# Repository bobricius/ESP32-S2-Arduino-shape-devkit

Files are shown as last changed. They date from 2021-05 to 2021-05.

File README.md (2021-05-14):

# ESP32-S2-Arduino-shape-devkit
Simplified Adafruit Metro ESP32-S2

ESP32-S2 development board.

Tested:

0.96" IPS display

#Circuitpython

Arduino IDE

DFU Bootloader

PCB Made in 

@AislerHQ www.aisler.net
 
Thanks 
@adafruit for great work!

Simplified Metro board.

DISPLAY:

  #define TFT_CS         7

  #define TFT_RST        5

  #define TFT_DC         6

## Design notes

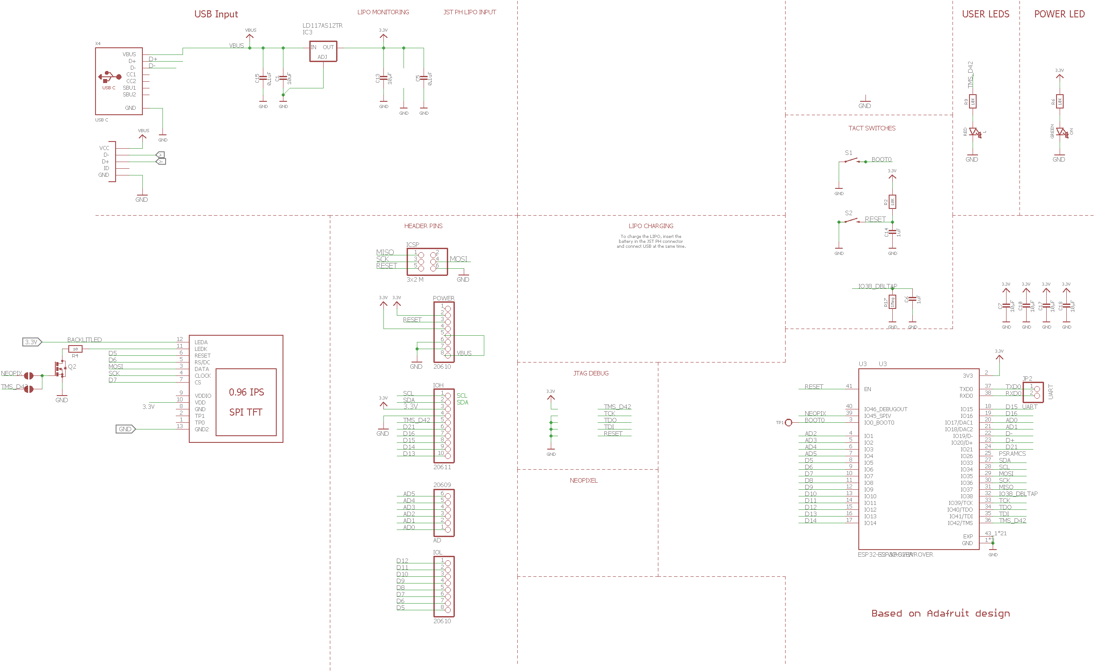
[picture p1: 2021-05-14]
schematic.png

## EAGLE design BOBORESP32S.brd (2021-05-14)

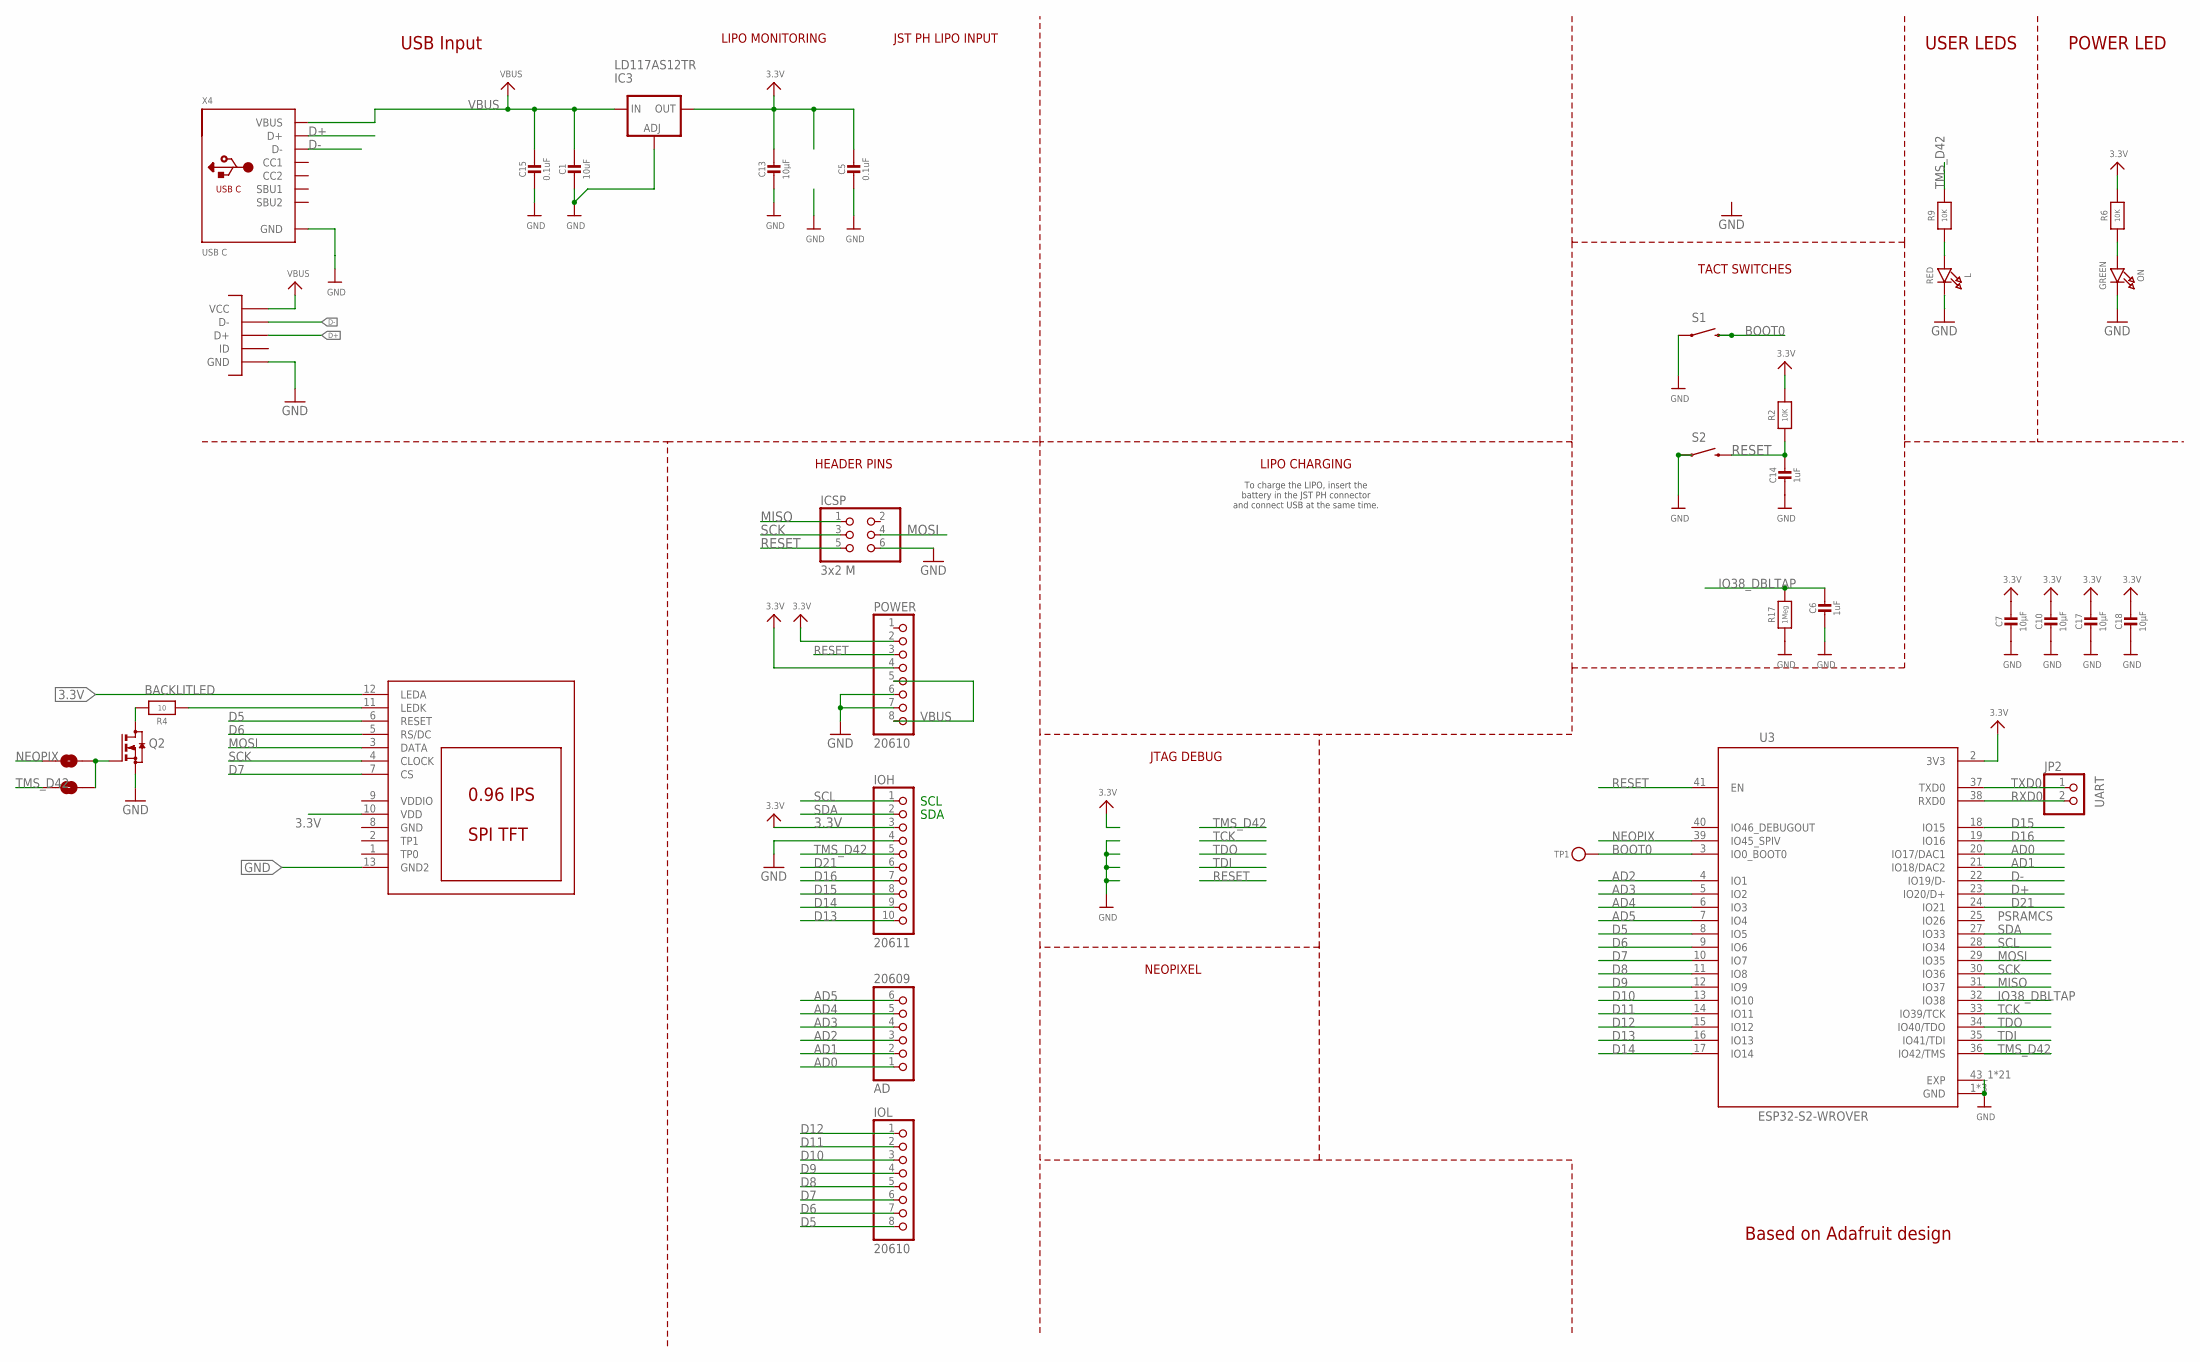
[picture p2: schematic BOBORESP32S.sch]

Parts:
AD: 20609; 1X06_OVALWAVE
C1: 10uF; _0805
C5: 0.1uF; _0805
C6, C14: 1uF; _0603
C7, C10, C13, C17, C18: 10µF; _0805
C15: 0.1uF; _0603
IC3: LD117AS12TR; SOT223
ICSP: 3x2 M; 2X03_ROUND_70MIL
IOH: 20611; 1X10_OVALWAVE
IOL: 20610; 1X08_OVALWAVE
JP2: UART; 1X02_ROUND
JUMPER1: SOLDERJUMPERTRACE; SJ_2S-TRACE
JUMPER2: SOLDERJUMPERNC2; SJ_2S-NOTRACE
L: RED; CHIPLED_0603_NOOUTLINE
ON: GREEN; CHIPLED_0603_NOOUTLINE
POWER: 20610; 1X08_OVALWAVE
Q2: BSS123; SOT23
R2, R6, R9: 10K; 0603-NO
R4: 10; 0603-NO
R17: 1Meg; 0603-NO
S1, S2: SWITCH-MOMENTARY-2PTH; TACTILE-PTH
TP1: TESTPOINTROUND1.5MMNO; TESTPOINT_ROUND_1.5MM_NO
U3: ESP32-S2-WROVER; MODULE_ESP32-S2-WROVER
U$5: MICROUSB; MICRO_B
U$9: DISP_LCD_0.9IN_160X80; TFT_0.96IN_160X80B
X4: USB C; USB_C_CUSB31-CFM2AX-01-X

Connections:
3.3V: C5.1, C7.1, C10.1, C13.1, C17.1, C18.1, IC3.4 (OUT), IOH.3, POWER.2, POWER.4, R2.2, R6.2, U3.2 (3V3), U$9.10 (VDD), U$9.12 (LEDA)
AD0: AD.1, U3.20 (IO17/DAC1)
AD1: AD.2, U3.21 (IO18/DAC2)
AD2: AD.3, U3.4 (IO1)
AD3: AD.4, U3.5 (IO2)
AD4: AD.5, U3.6 (IO3)
AD5: AD.6, U3.7 (IO4)
BACKLITLED: R4.1, U$9.11 (LEDK)
BOOT0: S1.3 (2), TP1.P$1, U3.3 (IO0_BOOT0)
D5: IOL.8, U3.8 (IO5), U$9.6 (RESET)
D6: IOL.7, U3.9 (IO6), U$9.5 (RS/DC)
D7: IOL.6, U3.10 (IO7), U$9.7 (CS)
D8: IOL.5, U3.11 (IO8)
D9: IOL.4, U3.12 (IO9)
D10: IOL.3, U3.13 (IO10)
D11: IOL.2, U3.14 (IO11)
D12: IOL.1, U3.15 (IO12)
D13: IOH.10, U3.16 (IO13)
D14: IOH.9, U3.17 (IO14)
D15: IOH.8, U3.18 (IO15)
D16: IOH.7, U3.19 (IO16)
D21: IOH.6, U3.24 (IO21)
D+: U3.23 (IO20/D+), U$5.P3 (D+), X4.A6 (D+), X4.B6 (D+)
D-: U3.22 (IO19/D-), U$5.P2 (D-), X4.A7 (D-), X4.B7 (D-)
DISPBL: JUMPER1.1, JUMPER2.1, Q2.1 (G)
GND: C1.2, C5.2, C6.2, C7.2, C10.2, C13.2, C14.2, C15.2, C17.2, C18.2, IC3.1 (ADJ), ICSP.6, IOH.4, L.C, ON.C, POWER.6, POWER.7, Q2.2 (S), R17.1, S1.1, S2.1, U3.1 (GND), U3.26 (GND), U3.42 (GND), U3.43_1 (EXP), U3.43_2 (EXP), U3.43_3 (EXP), U3.43_4 (EXP), U3.43_5 (EXP), U3.43_6 (EXP), U3.43_7 (EXP), U3.43_8 (EXP), U3.43_9 (EXP), U3.43_10 (EXP), U3.43_11 (EXP), U3.43_12 (EXP), U3.43_13 (EXP), U3.43_14 (EXP), U3.43_15 (EXP), U3.43_16 (EXP), U3.43_17 (EXP), U3.43_18 (EXP), U3.43_19 (EXP), U3.43_20 (EXP), U3.43_21 (EXP), U$5.GND1 (GND), U$5.GND2 (GND), U$5.GND3 (GND), U$5.GND4 (GND), U$5.GND7 (GND), U$5.GND8 (GND), U$5.P5 (GND), U$9.8 (GND), U$9.13 (GND2), X4.A1B12 (GND), X4.B1A12 (GND)
IO38_DBLTAP: C6.1, R17.2, U3.32 (IO38)
MISO: ICSP.1, U3.31 (IO37)
MOSI: ICSP.4, U3.29 (IO35), U$9.3 (DATA)
unnamed: L.A, R9.1
unnamed: Q2.3 (D), R4.2
unnamed: ON.A, R6.1
NEOPIX: JUMPER2.2, U3.39 (IO45_SPIV)
RESET: C14.1, ICSP.5, POWER.3, R2.1, S2.3 (2), U3.41 (EN)
RXD0: JP2.2, U3.38 (RXD0)
SCK: ICSP.3, U3.30 (IO36), U$9.4 (CLOCK)
SCL: IOH.1, U3.28 (IO34)
SDA: IOH.2, U3.27 (IO33)
TCK: U3.33 (IO39/TCK)
TDI: U3.35 (IO41/TDI)
TDO: U3.34 (IO40/TDO)
TMS_D42: IOH.5, JUMPER1.2, R9.2, U3.36 (IO42/TMS)
TXD0: JP2.1, U3.37 (TXD0)
VBUS: C1.1, C15.1, IC3.3 (IN), POWER.5, POWER.8, U$5.P1 (VCC), X4.A4B9 (VBUS), X4.B4A9 (VBUS)
VDDIO: U$9.9 (VDDIO)

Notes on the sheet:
SDA
SCL
Based on Adafruit design
USB Input
POWER LED
USER LEDS
LIPO CHARGING
LIPO MONITORING
To charge the LIPO, insert the battery in the JST PH connector and connect USB at the same time.
JST PH LIPO INPUT
HEADER PINS
TACT SWITCHES
JTAG DEBUG
NEOPIXEL
PSRAMCS

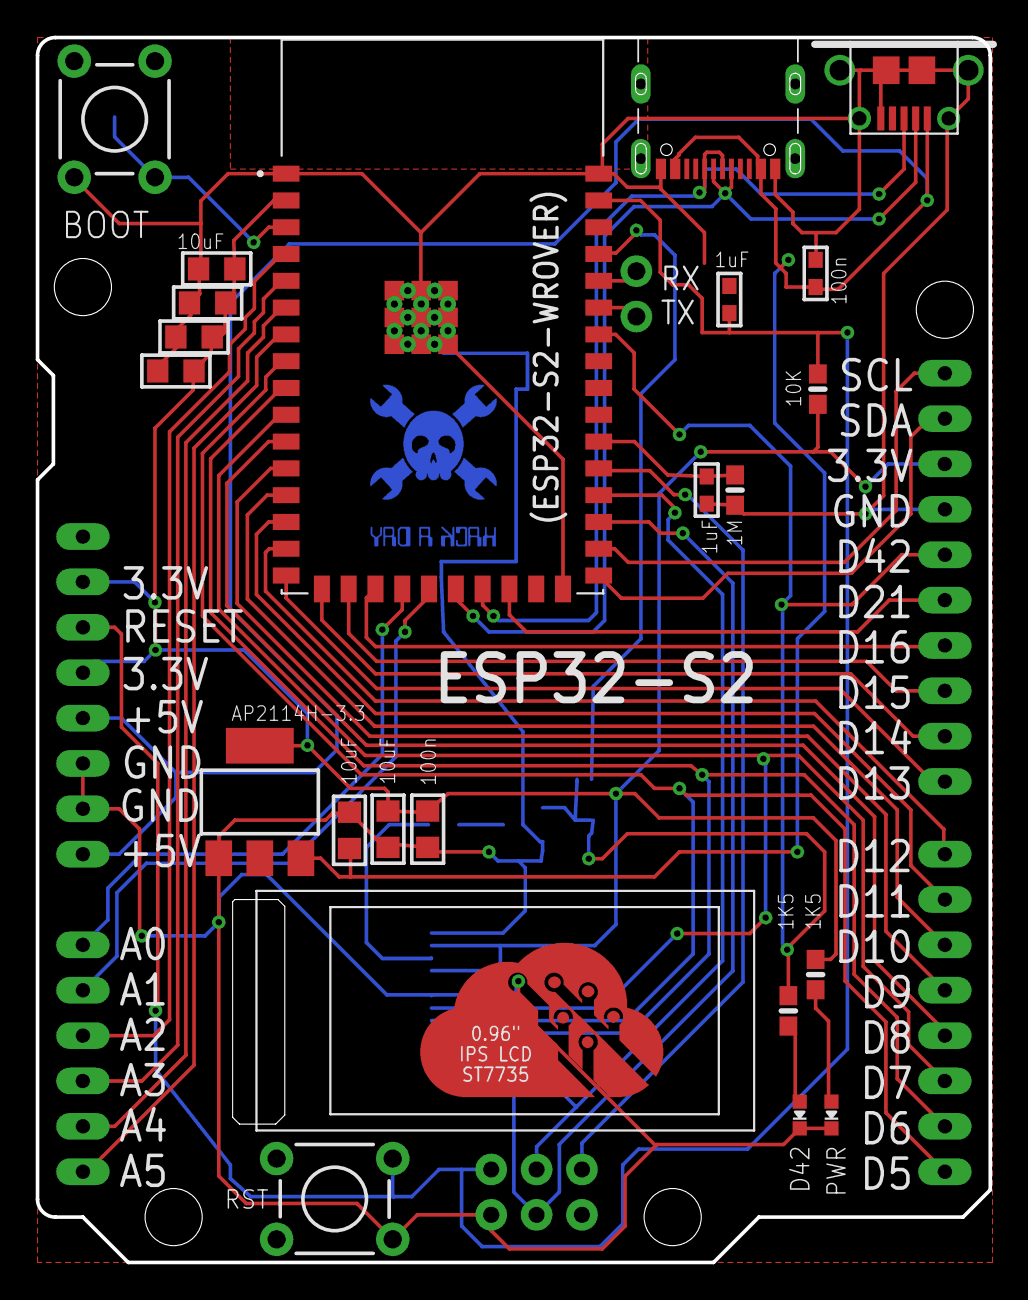
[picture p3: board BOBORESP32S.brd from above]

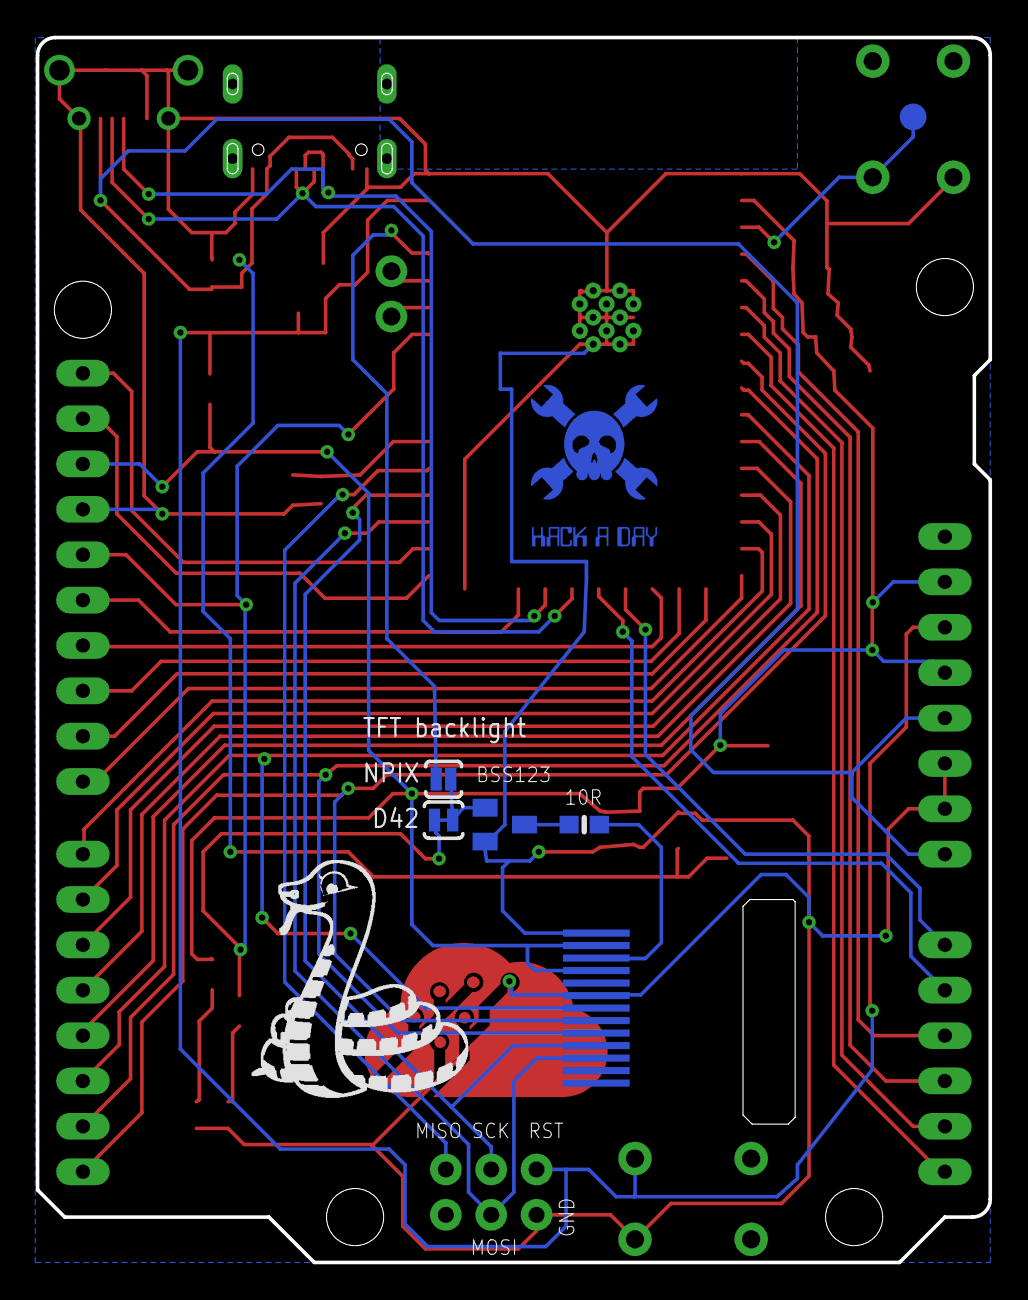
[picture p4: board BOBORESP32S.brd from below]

Board: 2 copper layers, 53.3 x 68.6 mm, 34 parts (5 on the bottom side), 41 nets.

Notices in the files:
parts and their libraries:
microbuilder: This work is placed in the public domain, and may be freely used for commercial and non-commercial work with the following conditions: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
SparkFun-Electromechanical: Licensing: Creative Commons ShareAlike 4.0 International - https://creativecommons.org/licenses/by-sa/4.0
